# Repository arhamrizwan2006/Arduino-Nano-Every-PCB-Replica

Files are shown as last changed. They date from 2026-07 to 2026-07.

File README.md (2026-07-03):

# Arduino Nano Every - Chip-Level PCB Replica

A full chip-level PCB replica of the Arduino Nano Every (ABX00028), designed from scratch in KiCad 10 - complete schematic, custom component creation, auto+manual routing, and manufacturing-ready output.

## Overview
This project replicates the official Arduino Nano Every board at the component level, rebuilding its schematic and PCB layout across five sub-circuits, verifying the design with zero DRC (Design Rule Check) errors, and generating full manufacturing files (Gerbers, drill files, BOM).

## Sub-Circuits Designed
1. MP2322 Power Regulator - voltage regulation circuit
2. ATmega4809 MCU - main microcontroller circuit
3. ATSAMD11D14A USB Bridge - USB-to-serial bridge controller
4. USB Micro-B Connector - power/data input
5. I/O Headers - 2x 15-pin connectors for digital/analog I/O

## PCB Layout
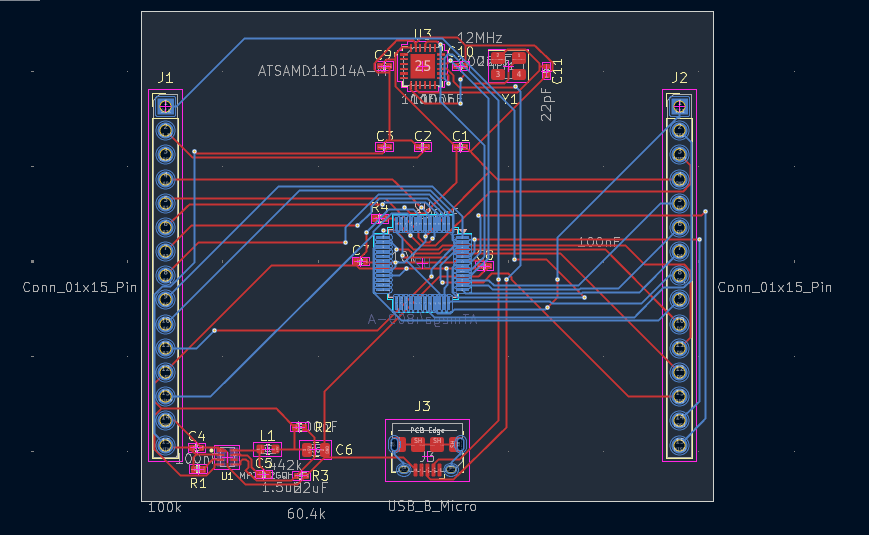
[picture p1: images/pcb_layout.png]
PCB Layout


## 3D Renders
Top and Bottom renders available in images/pcb_3d_top.png and images/pcb_3d_bottom.png

## Schematic
Full schematic available as PDF: images/schematic_overview.pdf

## Design Process
- Schematic captured across 5 sub-circuits in KiCad 10
- Custom footprint and 3D model created for the MP2322 regulator (not available in standard libraries) - see components/ folder
- PCB layout with auto-routing via FreeRouting v2.2.4, followed by manual trace completion for optimization
- Design Rule Check (DRC) run to zero errors before finalizing
- Full manufacturing output generated: Gerbers, drill files (PTH/NPTH), and Bill of Materials

## Repository Structure
kicad_project/
|-- NanoEvery_Replica.kicad_pro     - KiCad project file
|-- NanoEvery_Replica.kicad_sch     - Schematic
|-- NanoEvery_Replica.kicad_pcb     - PCB layout
|-- gerber_files/                    - Manufacturing-ready Gerber + drill files
|-- bom/                              - Bill of Materials (CSV)
|-- components/                       - Custom footprint, symbol, and 3D model (MP2322)
|-- images/                           - Schematic, PCB layout, and 3D render exports

## Bill of Materials
Full BOM available in bom/NanoEvery_Replica.csv

## Manufacturing Files
Gerber and drill files ready for fabrication are in gerber_files/

## What I Learned
- Full-board schematic design across multiple interconnected sub-circuits
- Creating custom footprints and 3D models for components not in standard libraries
- PCB auto-routing (FreeRouting) combined with manual routing optimization
- Design Rule Checking and achieving a fully clean (zero-error) layout
- Generating complete, fabrication-ready manufacturing outputs (Gerbers, drill files, BOM)

## Future Improvements
- Order and assemble a physical prototype to validate the design
- Add functional testing documentation once built

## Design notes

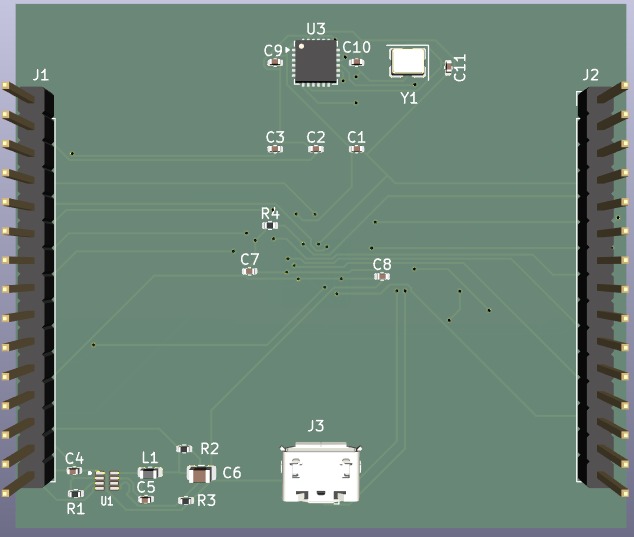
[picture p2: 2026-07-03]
images/pcb_3d_top.png

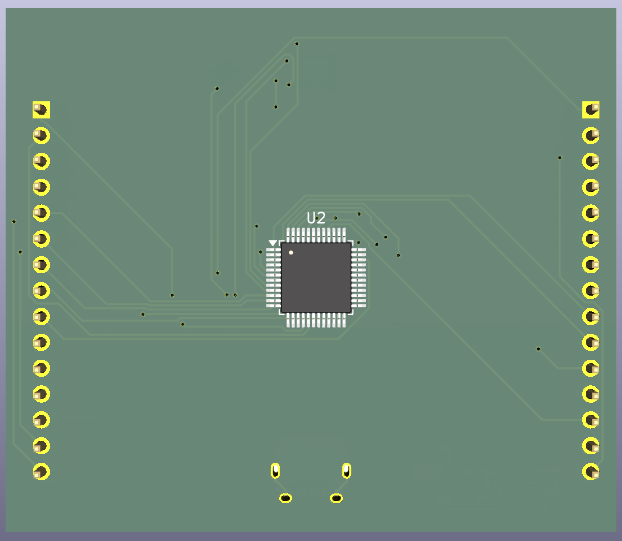
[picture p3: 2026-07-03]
images/pcb_3d_bottom.png

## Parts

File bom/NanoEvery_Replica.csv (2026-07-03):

Reference | Qty | Value | DNP | Exclude from BOM | Exclude from Board | Footprint | Datasheet
C1,C2,C4,C5,C7,C8,C9 | 7 | 100nF |  |  |  | Capacitor_SMD:C_0402_1005Metric
C3 | 1 | 10uF |  |  |  | Capacitor_SMD:C_0402_1005Metric
C6 | 1 | 22uF |  |  |  | Capacitor_SMD:C_0805_2012Metric
C10,C11 | 2 | 22pF |  |  |  | Capacitor_SMD:C_0402_1005Metric
J1,J2 | 2 | Conn_01x15_Pin |  |  |  | Connector_PinHeader_2.54mm:PinHeader_1x15_P2.54mm_Vertical
J3 | 1 | USB_B_Micro |  |  |  | Connector_USB:USB_Micro-B_Amphenol_10118194_Horizontal
L1 | 1 | 1.5uH |  |  |  | Inductor_SMD:L_0603_1608Metric
R1 | 1 | 100k |  |  |  | Resistor_SMD:R_0402_1005Metric
R2 | 1 | 442k |  |  |  | Resistor_SMD:R_0402_1005Metric
R3 | 1 | 60.4k |  |  |  | Resistor_SMD:R_0402_1005Metric
R4 | 1 | 10k |  |  |  | Resistor_SMD:R_0402_1005Metric
U1 | 1 | MP2322GQH-Z |  |  |  | MP2322_Footprint:CONV_MP2322GQH-Z
U2 | 1 | ATmega4809-A |  |  |  | Package_QFP:TQFP-48_7x7mm_P0.5mm | http://ww1.microchip.com/downloads/en/DeviceDoc/40002016A.pdf
U3 | 1 | ATSAMD11D14A-M |  |  |  | Package_DFN_QFN:QFN-24-1EP_4x4mm_P0.5mm_EP2.6x2.6mm | http://ww1.microchip.com/downloads/en/DeviceDoc/Atmel-42363-SAM-D11_Datasheet.pdf
Y1 | 1 | 12MHz |  |  |  | Crystal:Crystal_SMD_3225-4Pin_3.2x2.5mm

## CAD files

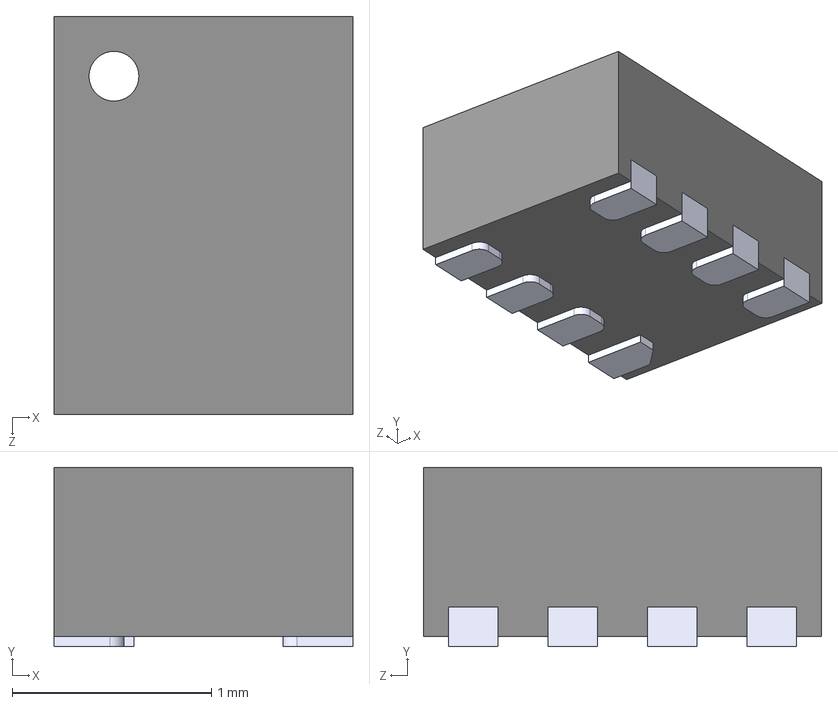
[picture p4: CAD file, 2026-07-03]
components/MP2322GQH-Z.step
1.50 x 0.9 x 2.00 mm

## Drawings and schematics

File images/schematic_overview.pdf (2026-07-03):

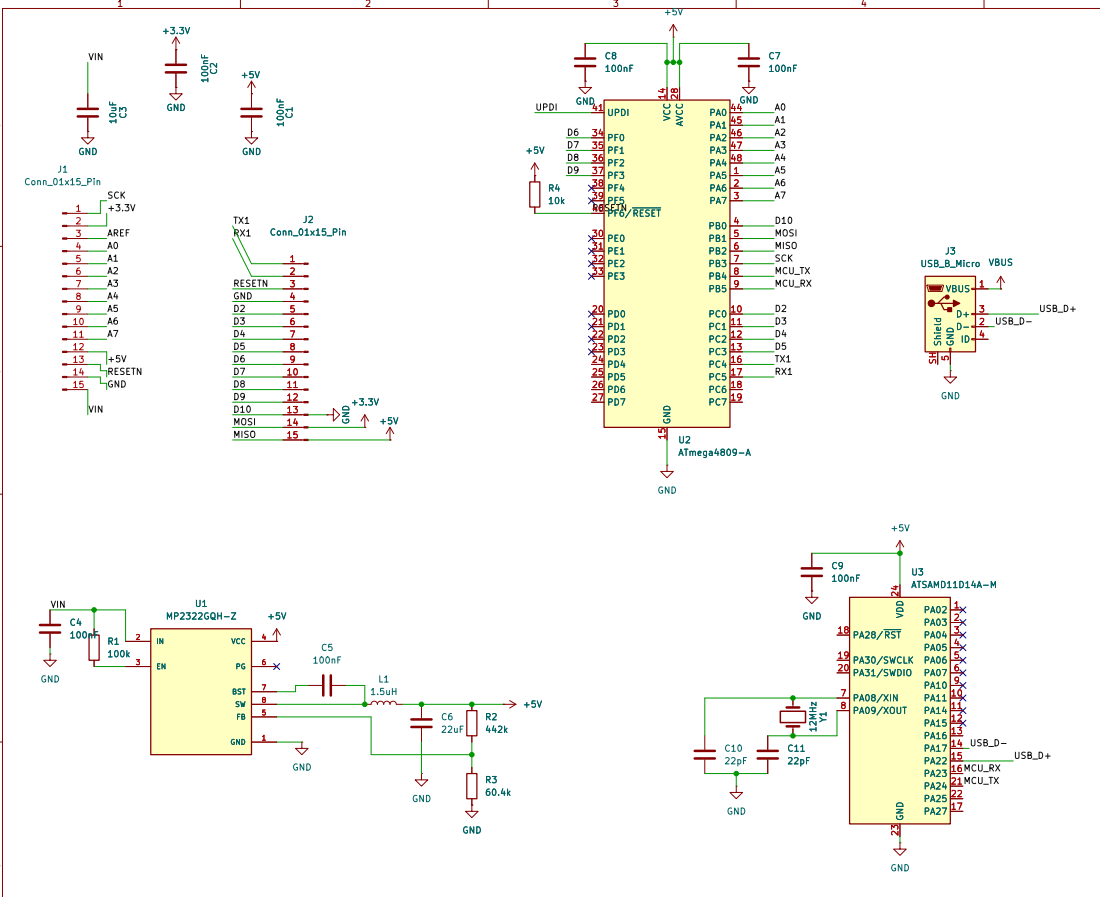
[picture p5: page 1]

Sheet: /
File: NanoEvery_Replica.kicad_sch
Title: Arduino Nano Every Replica

F Date: 2026-05-25

KiCad E.D.A. 10.0.3 | Id: 1/1

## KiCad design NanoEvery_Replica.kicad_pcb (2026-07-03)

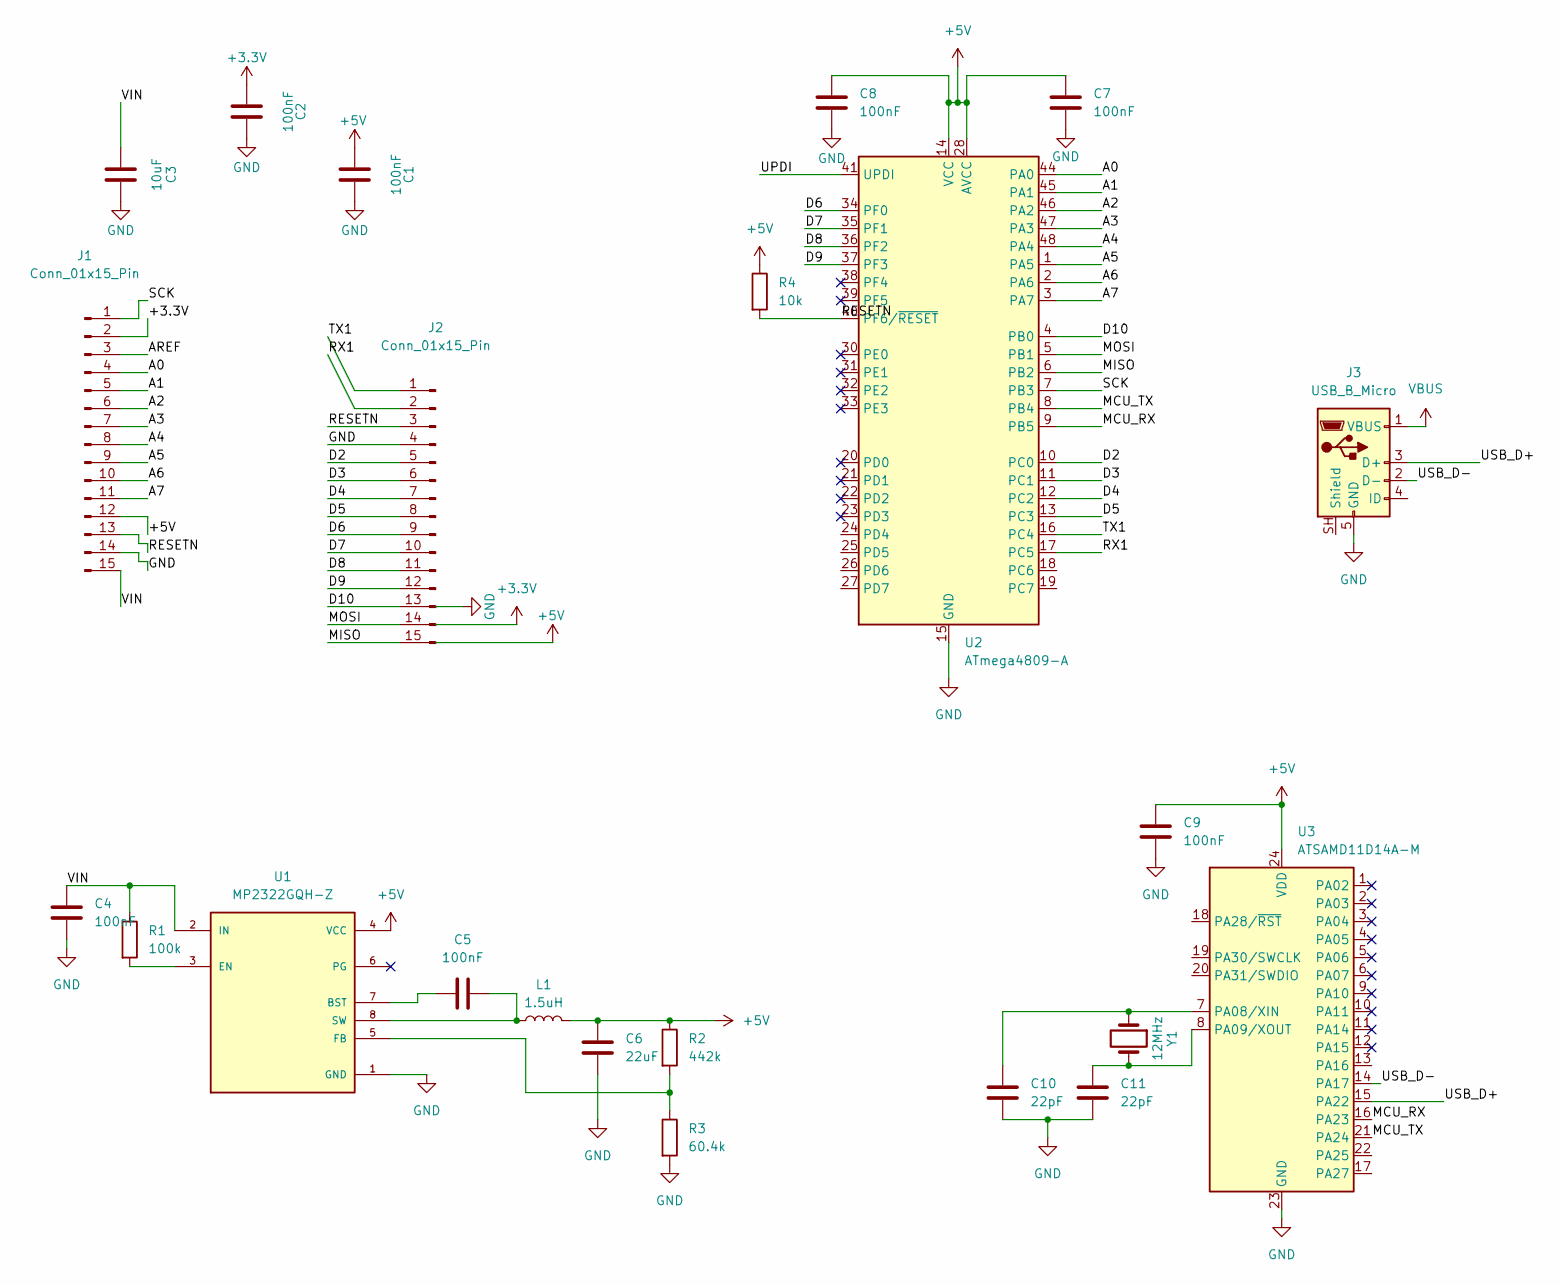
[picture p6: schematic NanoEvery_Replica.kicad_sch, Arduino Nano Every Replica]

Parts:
C1, C2, C4, C5, C7, C8, C9: 100nF; C_0402_1005Metric
C3: 10uF; C_0402_1005Metric
C6: 22uF; C_0805_2012Metric
C10, C11: 22pF; C_0402_1005Metric
J1, J2: Conn_01x15_Pin; PinHeader_1x15_P2.54mm_Vertical
J3: USB_B_Micro; USB_Micro-B_Amphenol_10118194_Horizontal
L1: 1.5uH; L_0603_1608Metric
R1: 100k; R_0402_1005Metric
R2: 442k; R_0402_1005Metric
R3: 60.4k; R_0402_1005Metric
R4: 10k; R_0402_1005Metric
U1: MP2322GQH-Z; CONV_MP2322GQH-Z; PARTREV 1.01; DigiKey_Part_Number 1589-MP2322GQH-ZCT-ND
U2: ATmega4809-A; TQFP-48_7x7mm_P0.5mm
U3: ATSAMD11D14A-M; QFN-24-1EP_4x4mm_P0.5mm_EP2.6x2.6mm
Y1: 12MHz; Crystal_SMD_3225-4Pin_3.2x2.5mm

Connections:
+3.3V: C2.2, J1.2
+5V: C1.1, C6.1, C7.1, C8.1, C9.1, J1.12, L1.2, R2.1, R4.1, U1.4 (VCC), U2.14 (VCC), U2.28 (AVCC), U2.42 (VCC), U3.24 (VDD)
/A0: J1.4, U2.44 (PA0)
/A1: J1.5, U2.45 (PA1)
/A2: J1.6, U2.46 (PA2)
/A3: J1.7, U2.47 (PA3)
/A4: J1.8, U2.48 (PA4)
/A5: J1.9, U2.1 (PA5)
/A6: J1.10, U2.2 (PA6)
/A7: J1.11, U2.3 (PA7)
/AREF: J1.3
/D2: J2.5, U2.10 (PC0)
/D3: J2.6, U2.11 (PC1)
/D4: J2.7, U2.12 (PC2)
/D5: J2.8, U2.13 (PC3)
/D6: J2.9, U2.34 (PF0)
/D7: J2.10, U2.35 (PF1)
/D8: J2.11, U2.36 (PF2)
/D9: J2.12, U2.37 (PF3)
/D10: J2.13, U2.4 (PB0)
/MCU_RX: U2.9 (PB5), U3.16 (PA23)
/MCU_TX: U2.8 (PB4), U3.21 (PA24)
/MISO: J2.15, U2.6 (PB2)
/MOSI: J2.14, U2.5 (PB1)
/RESETN: J1.13, J2.3, R4.2, U2.40 (PF6/~RESET)
/RX1: J2.2, U2.17 (PC5)
/SCK: J1.1, U2.7 (PB3)
/TX1: J2.1, U2.16 (PC4)
/UPDI: U2.41 (UPDI)
/USB_D+: J3.3 (D+), U3.15 (PA22)
/USB_D-: J3.2 (D-), U3.14 (PA17)
/VIN: C3.2, C4.1, J1.15, R1.1, U1.2 (IN)
GND: C1.2, C2.1, C3.1, C4.2, C6.2, C7.2, C8.2, C9.2, C10.2, C11.2, J1.14, J2.4, J3.5 (GND), R3.2, U1.1 (GND), U2.15 (GND), U2.29 (GND), U2.43 (GND), U3.23 (GND)
unnamed: C5.1, U1.7 (BST)
unnamed: R1.2, U1.3 (EN)
unnamed: R2.2, R3.1, U1.5 (FB)
unnamed: C5.2, L1.1, U1.8 (SW)
unnamed: C10.1, U3.7 (PA08/XIN), Y1.1
unnamed: C11.1, U3.8 (PA09/XOUT), Y1.2
VBUS: J3.1 (VBUS)

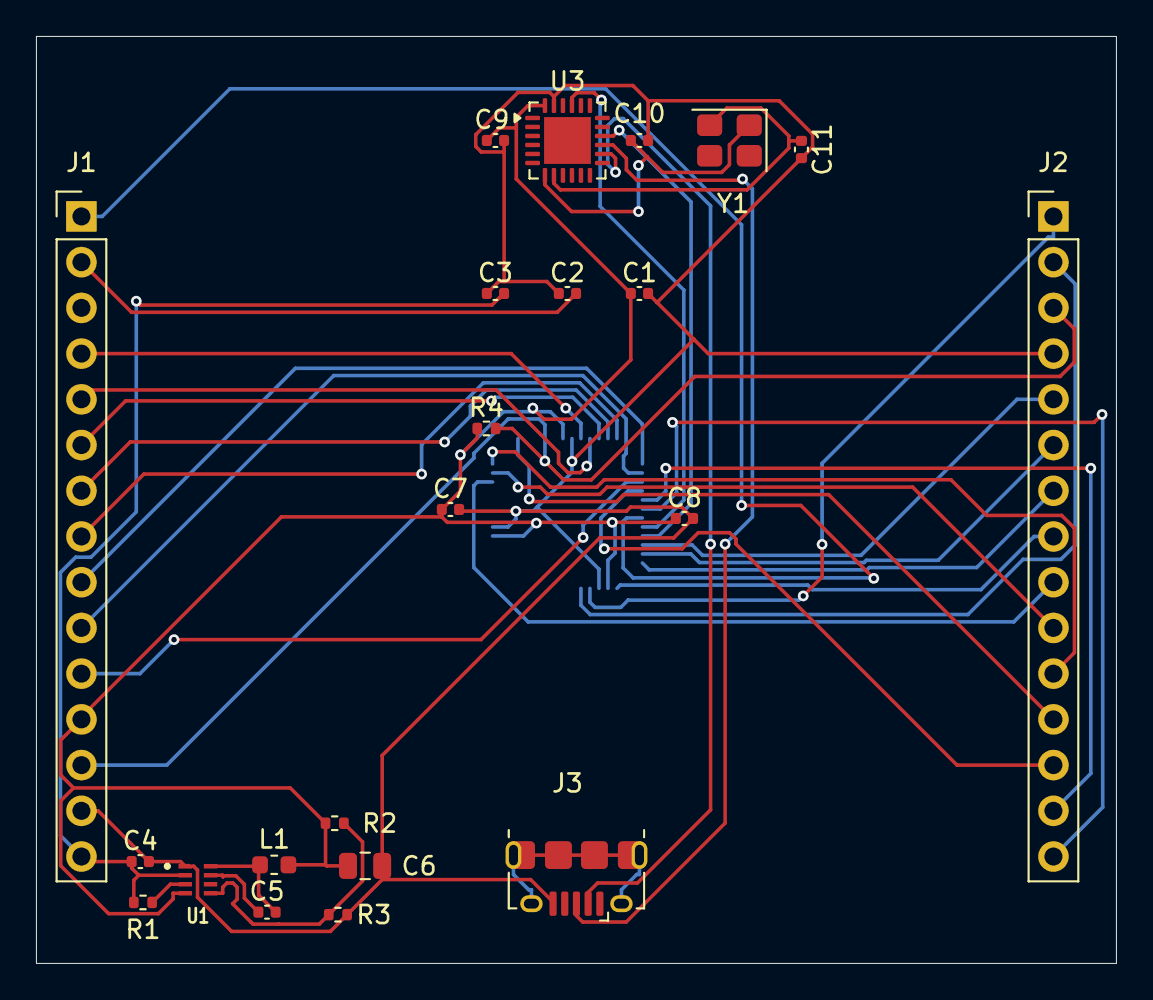
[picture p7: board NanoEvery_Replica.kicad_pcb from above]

Board: 2 copper layers, 60.0 x 51.5 mm, 23 parts (1 on the bottom side), 37 nets.
